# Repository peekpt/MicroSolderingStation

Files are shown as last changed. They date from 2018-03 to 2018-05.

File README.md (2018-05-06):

gif

# Micro Soldering Station

_Transform a cheap USB soldering iron in a powerfull Active tip Soldering Station._

**With almost no thermal capacity this station regulates the tip's temperature instantaneously. Solder larger thermal mass with ease, it's magic.**

_fiy: Active Soldering irons cost a lot of money_

*The cheapest Micro soldering Station ever:*

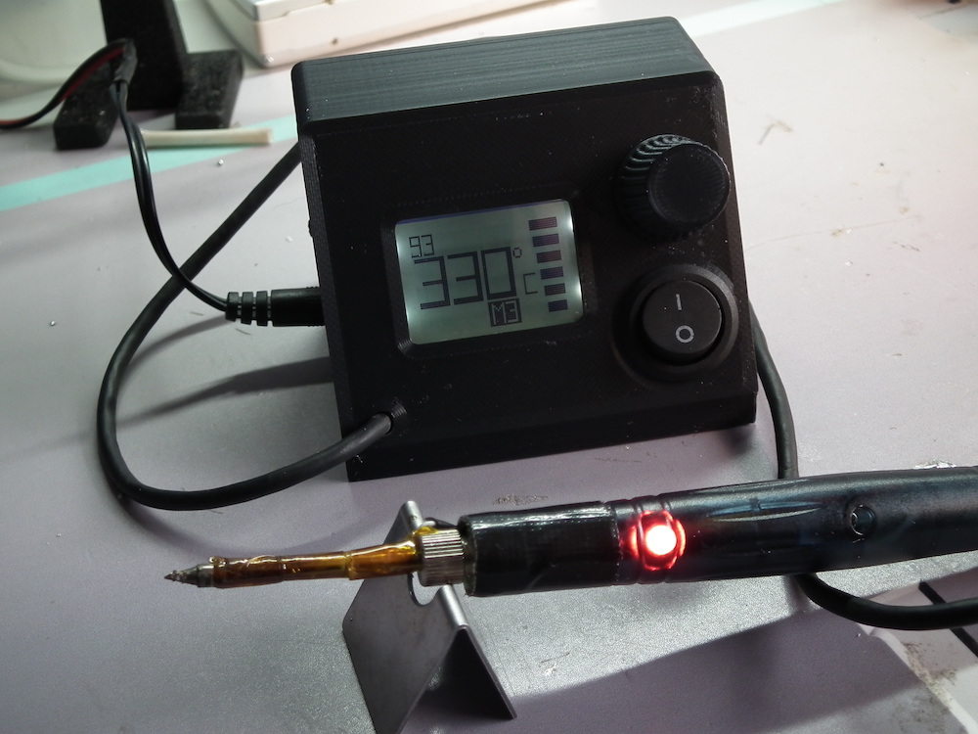
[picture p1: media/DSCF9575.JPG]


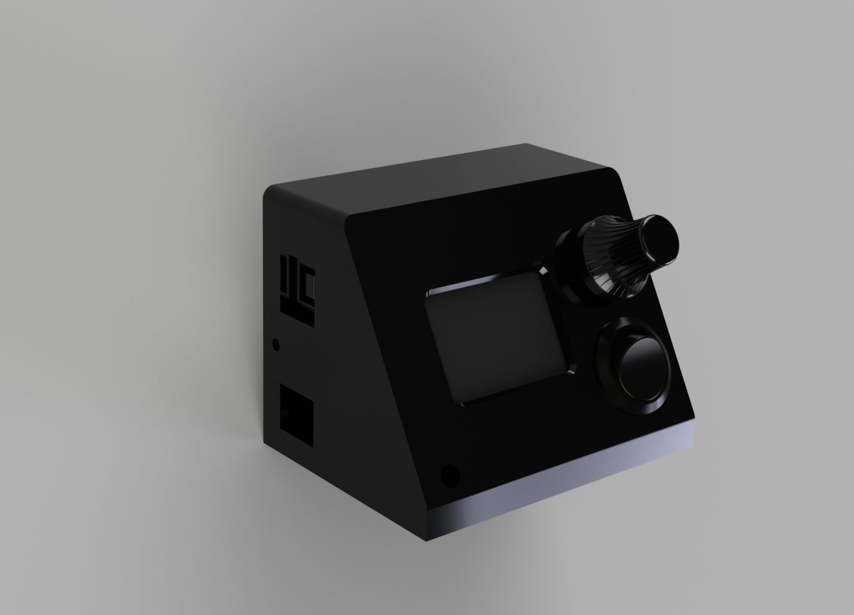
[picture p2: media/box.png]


## Youtube

YOUTUBE overview (https://www.youtube.com/watch?v=iJwf-qWp4lI)

YOUTUBE performance (https://www.youtube.com/watch?v=kRIv3psVogc)

## Features

- Cheap & easy build under 10$
- Temperature controled (PID)
- Memories
- Micro soldering tip
- Serial command interface
- Ploter (outputs usefull data) 
- Great User Interface with output power Bargraph
- UI Sounds, with temperature reached warning.
- Open Source Arduino based
- Firmware Updates
- 3D Printed Case
- Wake up from standby iron pickup detection (by temperature sensing)

## Materials

- 1x Arduino Uno
- 1x Nokia LCD Module
- 1x USB Soldering Iron
- 1x Thermistor 100k 3950
- 1x 4 wire wire cable(usb cable works)
- 1x 5mm Led
- 2x 1k resistor
- 1x 4,7k resitor
- 1x 10n Capacitor
- Kapton tape 10-20mm
- 1x N MosFet (or use the Iron's pcb one)
- 1x rocker switch
- 10 x small screws 2.5x5mm large head

## Schematic

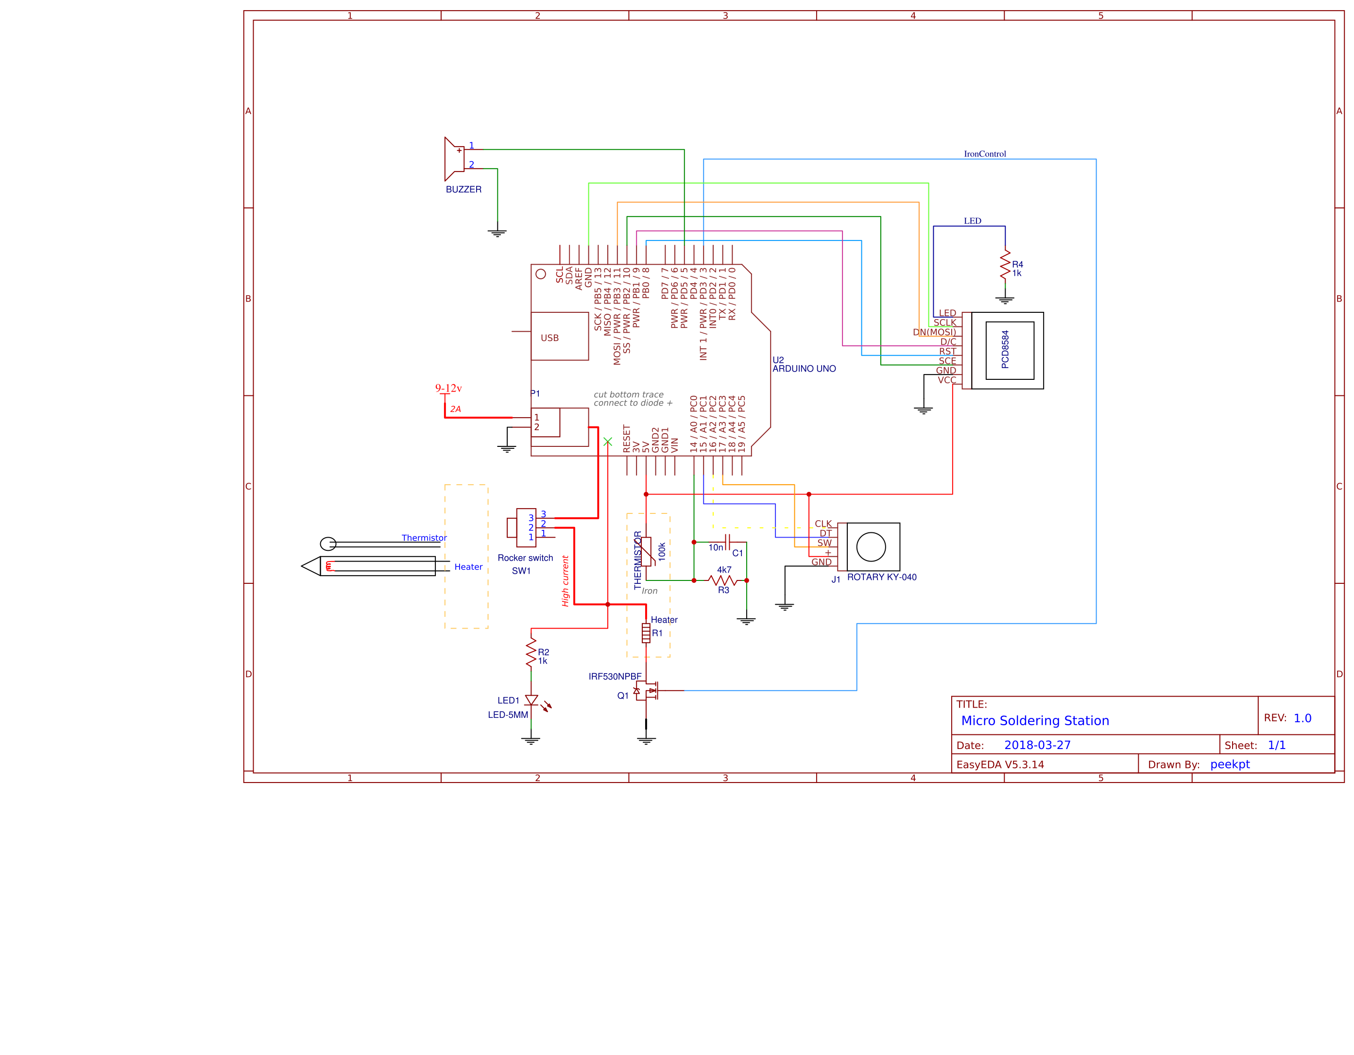
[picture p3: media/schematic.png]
Schematic


## Soldering Tip Diagram
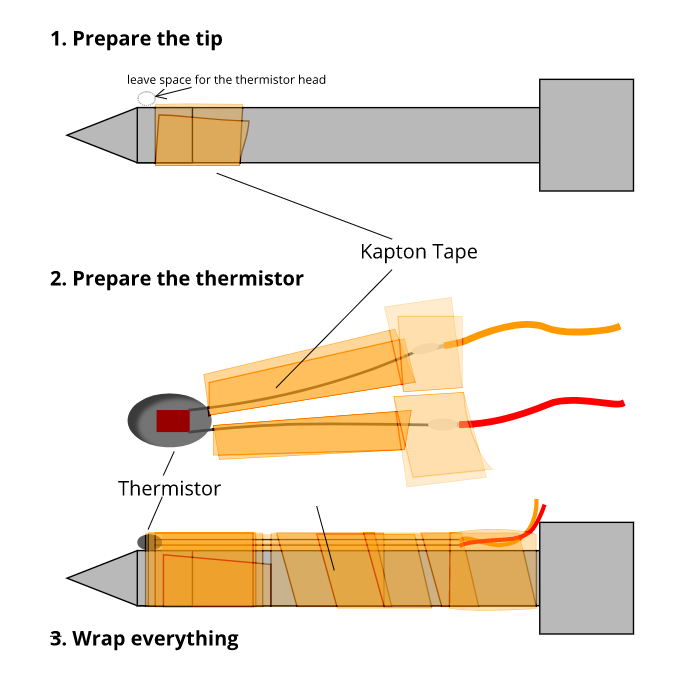
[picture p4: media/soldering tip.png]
Diagram


## UNO R3 CH340 Power Hack
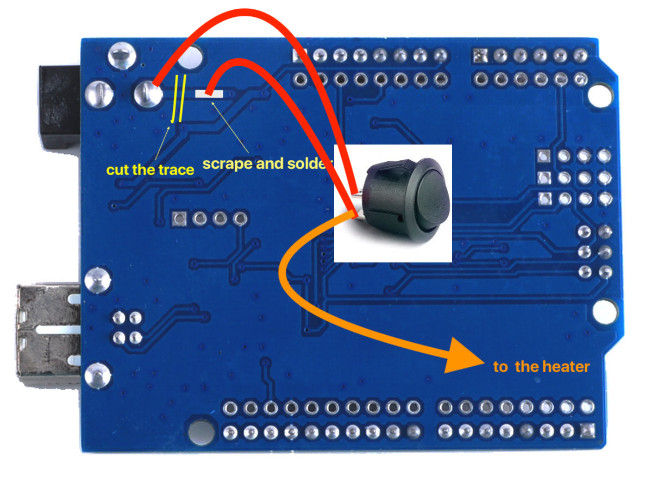
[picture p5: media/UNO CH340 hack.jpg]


_Cut Power the trace underneath the PCB and connect a rocker switch in series._

## Fritzing
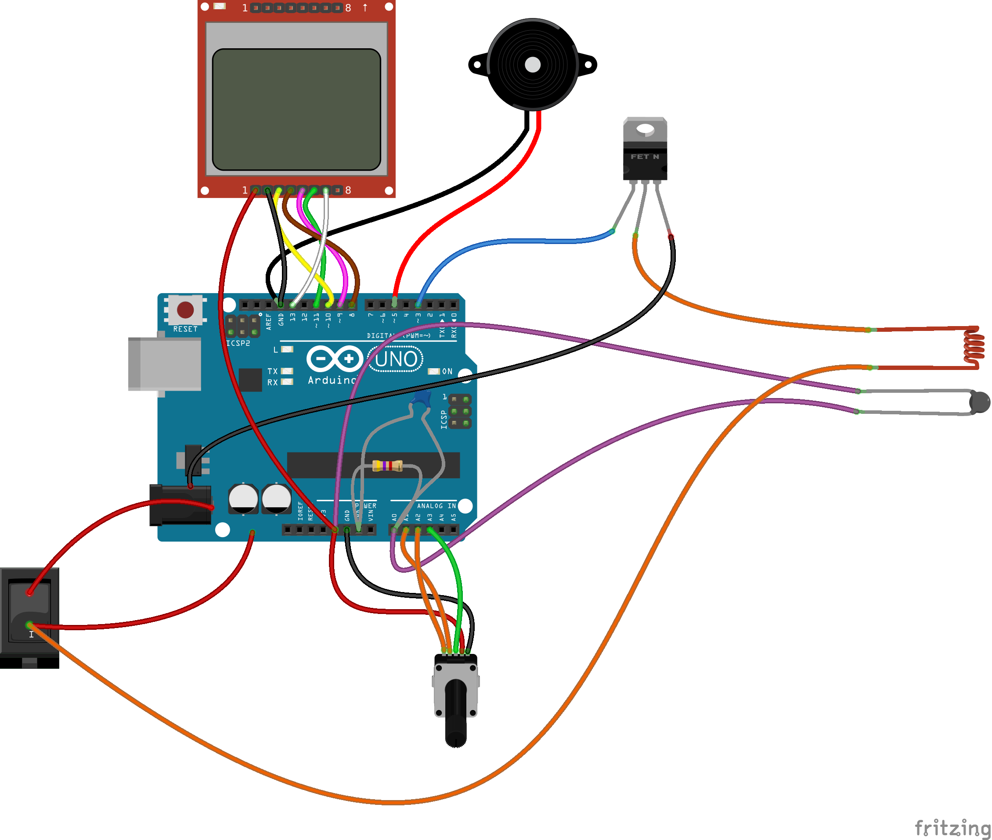
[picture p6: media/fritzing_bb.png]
Fritzing


Remove the pcb from the soldering iron and grab a cable with 4 wires (2 for thermistor, 2 for the heater).
Poke an hole in the side of the iron's case, near the yellow nut, to pass the 2 wires and solder them to the thermistor.
Use kapton tape to isolate the thermistor pins and to fix the thermistor's glass tip to the iron end with some kapton turns.
The other 2 wires connect to the heater and the led with a resistor in series. (watch the polarity of the led)
Remove the ball bearing and connect the led in the hole, break the spring post from the other side of the case.

## User Interface Screenshots
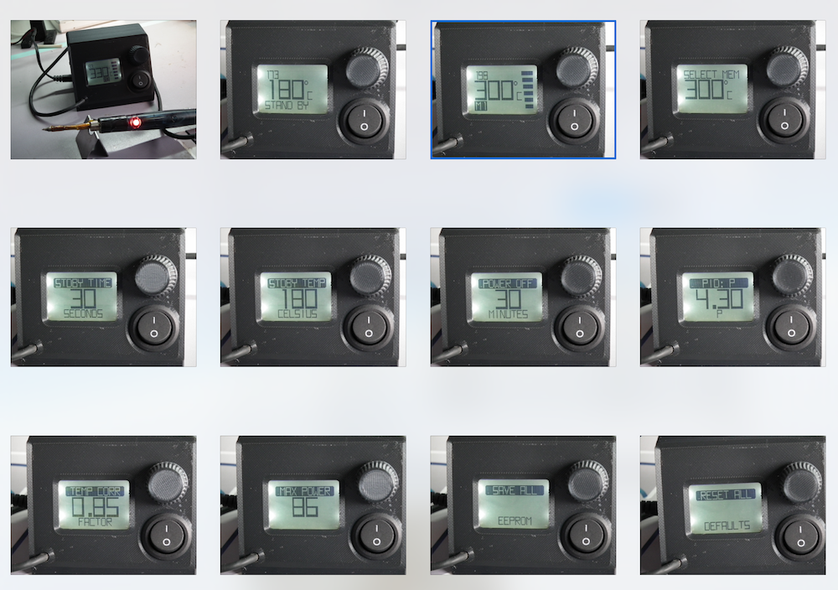
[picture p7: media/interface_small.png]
UNO


## Operation

**main view**

- \< >                   temp up down
- [click]                cycle memories
- [click & hold]         store mem mode
- [double click]         settings mode

**stand by mode**
- [click]                  leave standby mode

**store mem**
- \< >                   select memory to store
- [click]                store

**settings mode submenus**
 - \< >                   navigate submenus
 - [click]                edit submenu

**edit submenu**
- \< >                   change value up down
- [click]                exit submenu

## ChangeLog

2018-4-11

- interfance feedback sounds, you can disable on settings
- temperature reached beep 

2018-4-9

- improved automatic pickup detection (must be more improved in the future)
- you can now choose the type of wake up from standby between manual (by clicking) or automatic (by temperature) 

## Parts & Modules ##

100k thermistor (3950):

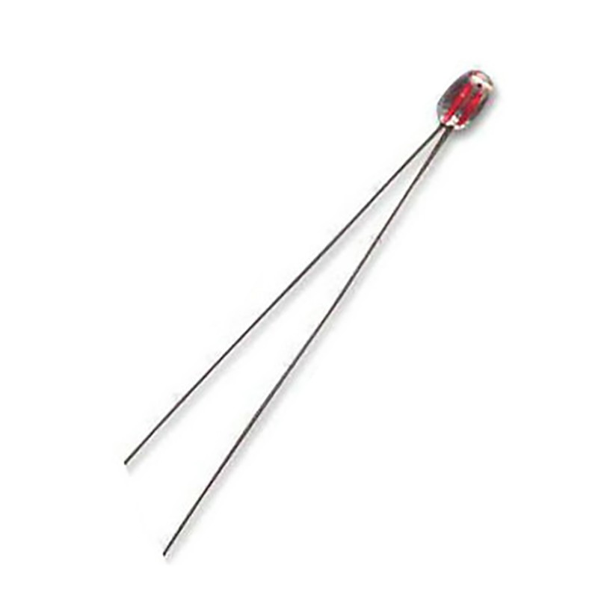
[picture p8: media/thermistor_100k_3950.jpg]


Arduino Uno R3 ch340:

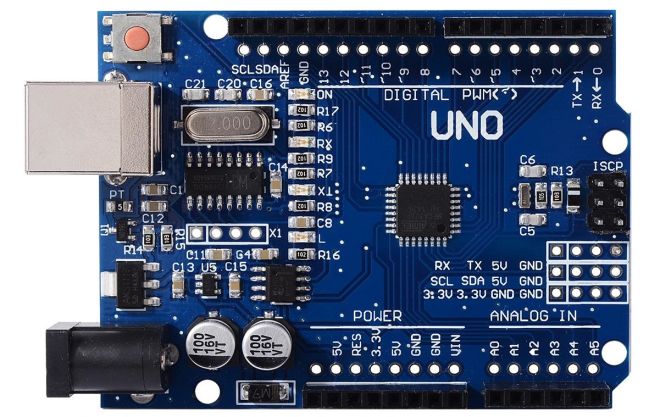
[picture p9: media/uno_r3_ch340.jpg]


Rotary Encoder:

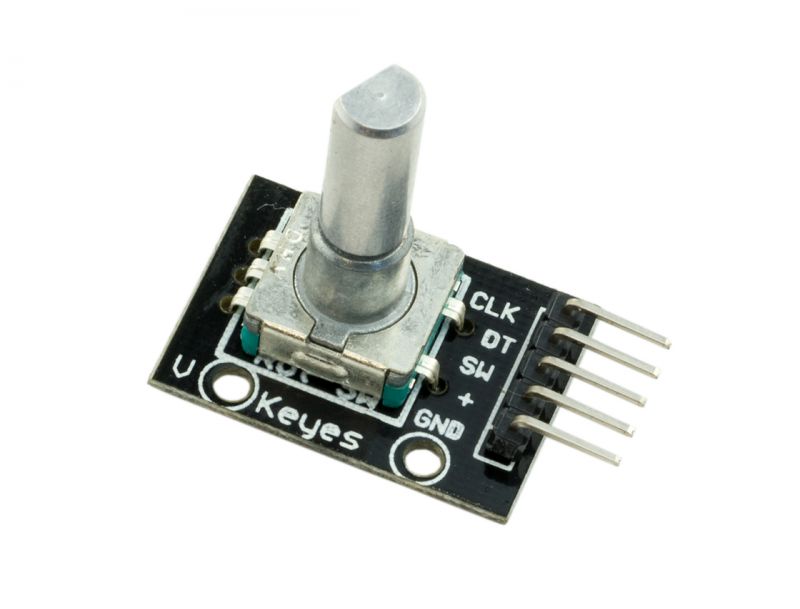
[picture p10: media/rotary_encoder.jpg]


USB Soldering Iron:

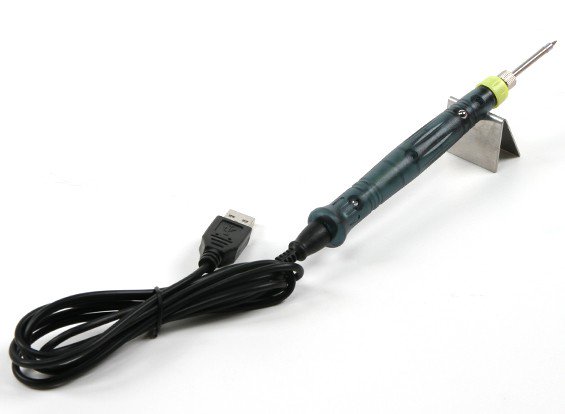
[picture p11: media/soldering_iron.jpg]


LCD:

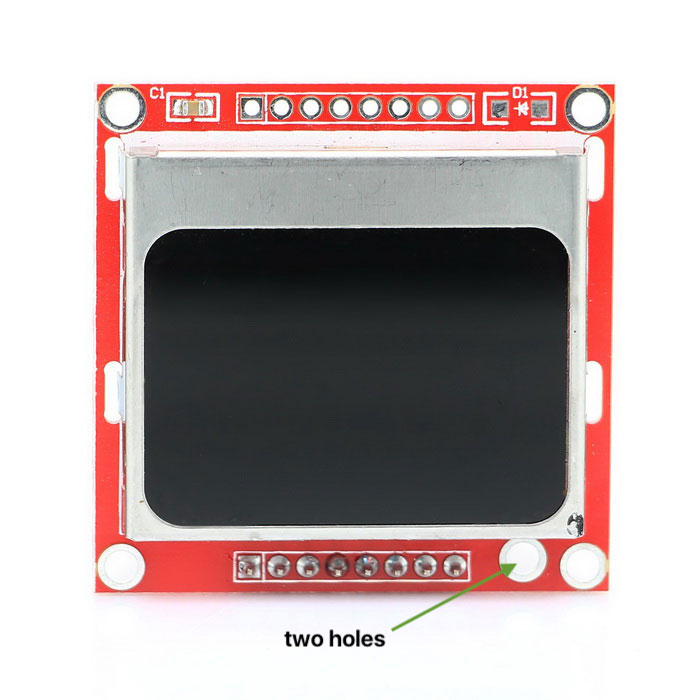
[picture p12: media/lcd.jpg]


Switch:

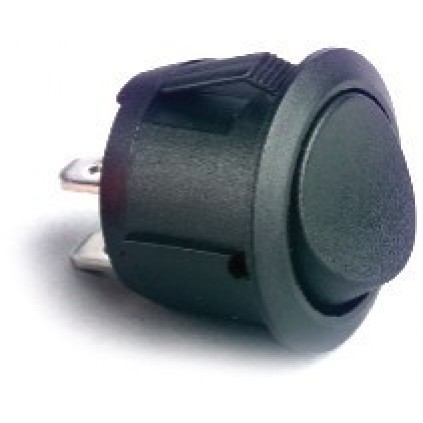
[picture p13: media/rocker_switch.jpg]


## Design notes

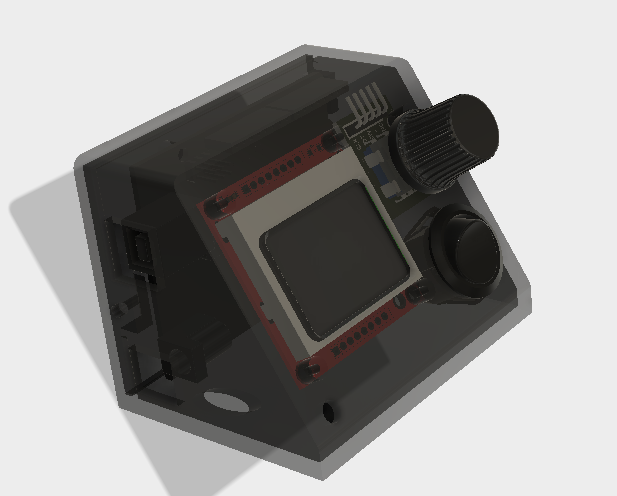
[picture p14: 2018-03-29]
media/transparent box.png

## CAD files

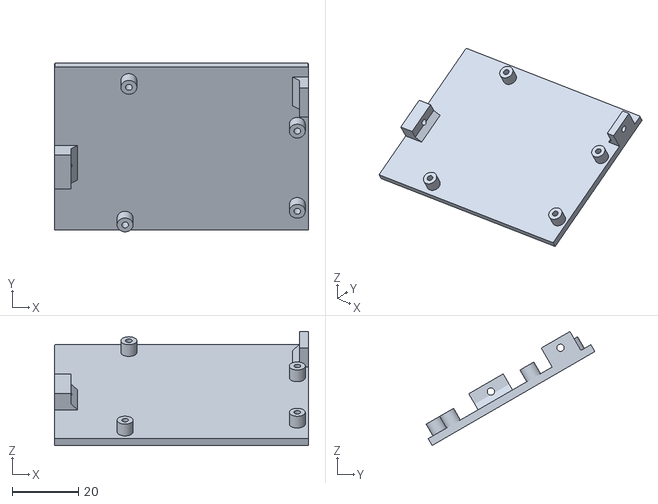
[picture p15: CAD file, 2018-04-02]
3D Box/soldering Station Box 2.stl
76.6 x 50.9 x 34.4

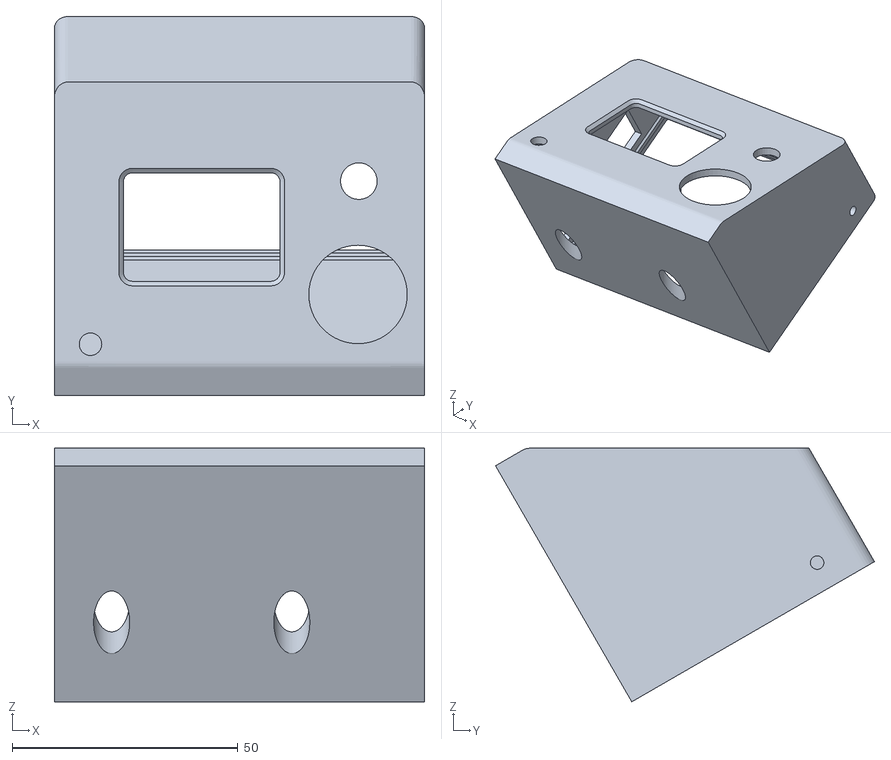
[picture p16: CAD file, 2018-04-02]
3D Box/soldering Station Box 1.stl
82.0 x 83.9 x 56.2

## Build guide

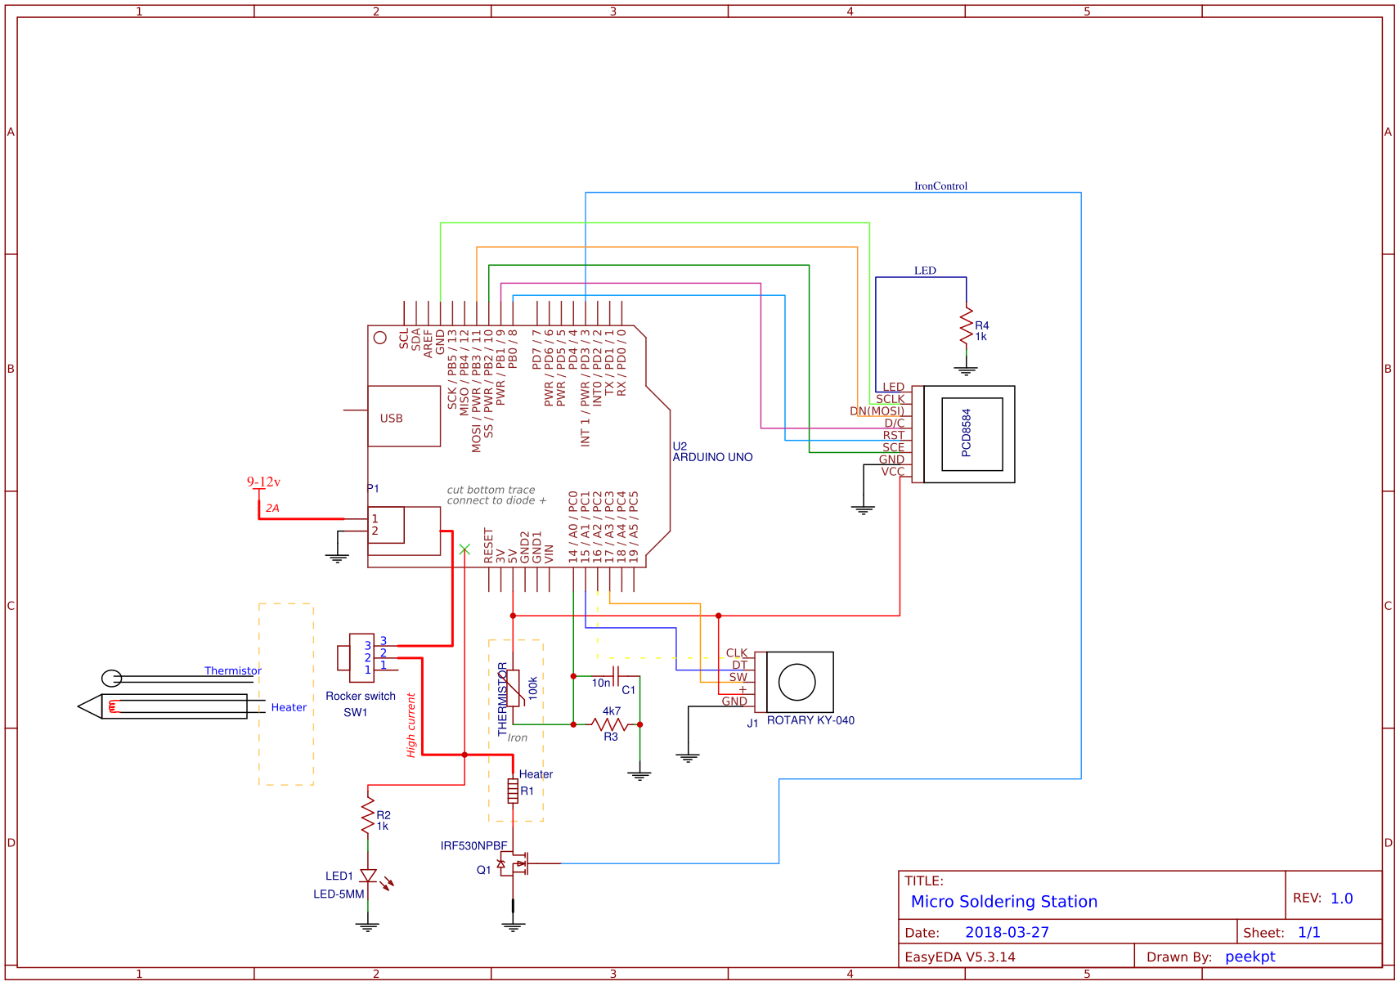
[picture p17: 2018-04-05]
media/Schematic_MicroSolderingStation_Micro-Soldering-Station_20180405173110.png

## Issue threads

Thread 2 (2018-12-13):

Power supply

caracolmaker, 2018-12-13:
What power source do you use for that project? I have a house from an old 12v and 1.5 amp laptop, would it work for the project?

peekpt, 2018-12-13:
Use platformio ide, open the folder and main.cpp then then plug your
Arduino and run

Na(o) quinta, 13/12/2018, 19:34, caracolmaker <notifications@github.com>
escreveu:

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

caracolmaker, 2018-12-15:
What power supply do you use foro this proyect.?

peekpt, 2018-12-15:
I use a simple 12v 2A wall charger, don't go over 14v the amp of the
Arduino uno can burn

caracolmaker <notifications@github.com> escreveu no dia sábado, 15/12/2018
à(s) 18:18:

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

caracolmaker, 2018-12-16:
Thank you

Closed 2018-12-16.

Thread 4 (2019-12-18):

Display problem

shark159, 2019-12-18:
Hello sir, I tried to compile this code for arduino nano,
i change some line and it compile and upload perfectly.
the problem is that after reboot the image stay on very frew seconds then disapear.
the conections are wired corectly,

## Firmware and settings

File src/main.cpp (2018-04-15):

#include <Arduino.h>
#include "SmoothThermistor.h"
#include <PID_v1.h>
#include <EEPROM.h>
#include <ClickEncoder.h>
#include <TimerOne.h>
#include <U8glib.h>
#include "avr/wdt.h"
#include "bitmap_logo.h"
#include "config.h"


enum VIEW { VIEW_LOGO, VIEW_MAIN, VIEW_SETTINGS } view;
enum MEM { MEM1, MEM2, MEM3 } mem;

const char *title[] = {"EXIT",   "STDBY TIME", "STDBY TEMP", "RESTORE",   "POWER OFF", "SOUNDS",   "PID: P",
                       "PID: I", "PID: D",     "TEMP CORR",  "MAX POWER", "SAVE ALL",  "RESET ALL"};
enum MENU {
  // it should match title array, this way it's easier to add more menus later
  MENU_EXIT = 0,
  MENU_SB_TIME,
  MENU_SB_TEMP,
  MENU_RESTORE,
  MENU_PWR_OFF,
  MENU_SOUND,
  MENU_P,
  MENU_I,
  MENU_D,
  MENU_T_CORR,
  MENU_MAX_PWR,
  MENU_SAVE_ALL,
  MENU_RESET_ALL,
  MENU_LENGHT // easy way having the menu lenght
} menu_e;
byte menuPosition;

byte memoryToStore;
ClickEncoder *encoder;
int16_t encLast, encValue;

double Setpoint, Input, Output, serialMillis, lcdMillis, logoMillis, blinkMillis, functionTimeout, standByMillis,
    tempBeforeEnteringStandby;
bool isDisplayingLogo, blink, isSavingMemory, isOnStandBy, isPlotting;

// measuring the temp variation per second
double tempVariation;
double oldTemp;
double tempMillis;
bool beepAtSetpoint;

// settings menu vars;
bool isEditing;
const char *topText;
const char *bottomText;
bool isFastCount;
int i;
double d;

typedef struct EepromMap {
  byte firstBoot;     // check for a number 123
  double standbyTemp; // temperature on stand-by
  unsigned int standbyTime;
  double p;           // p
  double i;           // i
  double d;           // d
  double m1;          // memory 1
  double m2;          // memory 2
  double m3;          // memory 3
  double tCorrection; // thermistor reading temperature correction factor
  byte maxPower;
  unsigned int timeout; //  seconds to standby
  byte lastMem;         // lastMemory selected
  bool sound;           // sound on /off
  bool restore;         // 0 manual 1 auto

} eeprom_map_t;

eeprom_map_t settings;


U8GLIB_PCD8544 u8g(LCD_CS,LCD_A0, LCD_RST); // uses 13 ,11 as Hardware pins 10-CS 9-A0 8-RS

// void setPwmFrequency(int, int); // sets pwm frequency divisor
double getTemp();             // read thermistor temp
void resetFailSafe();         // reset all eeprom to default
void printTunnings();         // outputs de pid settings
void draw();                  // displays a view
void updateLCD();             // updateLCD
void viewLogo();              // logo view
void viewMain();              // main view layout
void viewSettings();          // settings view layout
void software_Reboot();       // reboots
void timerIsr();              // rotary switch interrupt
void rotaryMain();            // rotary Main routines
void cicleMem();              // cicle ...MEM1->MEM2->MEM3->MEM1...
void resetTimeouts();         // reset    all timouts running to millis()
void drawMemIcon(byte);       // draws the given memory icon
void resetStandby();          // reset standby time count down
void rotarySettings();        // process rotary on the settings view
void drawTitle(const char *); // draws the title inverse bar on the settings menu
void beep();                  // sound 
void beepBeep();
void beepBop();
void bop();
void bopLong();

SmoothThermistor therm(SENSOR_PIN,      // the analog pin to read from
                       ADC_SIZE_10_BIT, // the ADC size
                       100000,          // the nominal resistance
                       4700,            // the series resistance
                       3950,            // the beta coefficient of the thermistor
                       25,              // the temperature for nominal resistance
                       10);             // the number of samples to take for each measurement

PID myPID(&Input, &Output, &Setpoint, 0, 0, 0, DIRECT);

void setup() {
  Serial.begin(9600);
  Serial.println(F("* START *"));

  tempVariation = 0;
  oldTemp = getTemp();
  // input and output pins
  pinMode(SENSOR_PIN, INPUT);
  pinMode(HEATER_PIN, OUTPUT);
  pinMode(BUZZER_PIN, OUTPUT);

  // rotary encoder
  encoder = new ClickEncoder(A1, A2, A3); // A, B, BTN
  encoder->setAccelerationEnabled(true);
  Timer1.initialize(1000);
  Timer1.attachInterrupt(timerIsr);
  // encLast = -1;
  encLast = encValue = encoder->getValue();

  // LCD
  u8g.setColorIndex(1);
  view = VIEW_LOGO; // display logo view.
  updateLCD();
  isDisplayingLogo = true;

  // heater
  // setPwmFrequency(HEATER_PIN, 1);
  analogWrite(HEATER_PIN, 0); // set heater to 0

  lcdMillis = serialMillis = logoMillis = blinkMillis = standByMillis = millis(); // delay routines

  // Load EEPROM
  EEPROM.get(0, settings);
  if (settings.firstBoot != 123) { // if the check number is not present then save settings
    resetFailSafe();
  }
  myPID.SetTunings(settings.p, settings.i, settings.d);
  printTunnings();

  Input = getTemp();
  //  choose last selected memory setpoint temperature
  switch (settings.lastMem) {
  case MEM1:
    Setpoint = settings.m1;
    break;
  case MEM2:
    Setpoint = settings.m2;
    break;
  case MEM3:
    Setpoint = settings.m3;
    break;
  default:
    Setpoint = 150;
  }
  tempBeforeEnteringStandby = Setpoint;

  myPID.SetMode(AUTOMATIC);                    // enable pid controller
  myPID.SetOutputLimits(0, settings.maxPower); // limits heater pwm duty cycle

  u8g.setColorIndex(0);
  u8g.drawBox(0, 0, 84, 48);
  u8g.setColorIndex(1);
  blink = false;
  isSavingMemory = false;
  memoryToStore = settings.lastMem;
  functionTimeout = 0;
  isOnStandBy = false;
  menuPosition = 0;
  isFastCount = false;
  isPlotting = false;
  beepAtSetpoint = true;
  beep();
}

void loop() {
  // serial input control
  if (Serial.available() > 0) {
    String strInput = Serial.readString();
    String command = strInput.substring(0, 2);
    double value = strInput.substring(2, strInput.length()).toDouble();
    if (command == "p:") {
      Serial.print(F("changed P value to: "));
      myPID.SetTunings(value, myPID.GetKi(), myPID.GetKd());
      Serial.println(myPID.GetKp());
    } else if (command == "i:") {
      Serial.print(F("changed I value to: "));
      myPID.SetTunings(myPID.GetKp(), value, myPID.GetKd());
      Serial.println(myPID.GetKi());
    } else if (command == "d:") {
      Serial.print(F("changed D value to: "));
      myPID.SetTunings(myPID.GetKp(), myPID.GetKi(), value);
      Serial.println(myPID.GetKd());
    } else if (command == "t") {
      printTunnings();
    } else if (command == "t:") {
      Serial.print(F("Setpoint: "));
      Setpoint = value;
      Serial.println(Setpoint);
    } else if (command == "s") {
      // save settings
      settings.p = myPID.GetKp();
      settings.i = myPID.GetKi();
      settings.d = myPID.GetKd();
      EEPROM.put(0, settings);
      Serial.println(F("Settings saved!"));
    } else if (command == "r") {
      resetFailSafe();
    } else if (command == "pl") {
      isPlotting = !isPlotting;
    } else {
      Serial.println(F("Unknown command!"));
    }
  }

  // rotary
  if (view == VIEW_MAIN) {
    rotaryMain();
  } else if (view == VIEW_SETTINGS) {
    rotarySettings();
  }

  // logo delay
  if (isDisplayingLogo) {
    if (millis() - logoMillis > 2000) { // show logo for 4 seconds
      view = VIEW_MAIN;
      isDisplayingLogo = false;
      updateLCD();
      resetStandby();
    }
  }

  // standby time
  if (!isOnStandBy) {
    if (millis() - standByMillis > (1000 * settings.standbyTime)) {
      tempBeforeEnteringStandby = Setpoint;
      Setpoint = settings.standbyTemp;
      isOnStandBy = true;

    }
  }

  // Control temperature
  Input = getTemp();
  if (Input < 0 || Input > 450) { // some protection
    myPID.SetMode(MANUAL);
    analogWrite(HEATER_PIN, 0);
    pinMode(HEATER_PIN, INPUT);
    view = VIEW_LOGO;
  }
  myPID.Compute();
  analogWrite(HEATER_PIN, Output);

  // LCD Update
  if (millis() - lcdMillis > 250) { // lcd update delay
    blink = !blink;
    updateLCD();
    lcdMillis = millis();
  }

  // function timeout
  if (millis() - functionTimeout > 20000) {
    // only permits 20 seconds without action outside main
    // functionTimeout needs to be reset to millis() in every rotary event
    // or it will call main screen
    isSavingMemory = false;
    view = VIEW_MAIN;

    updateLCD();
  }

  // temperature delta per second
  if (millis() - tempMillis > 1000) {
    double newTemp = getTemp();
    tempVariation = (newTemp / oldTemp) - 1;
    oldTemp = newTemp;
    tempMillis = millis();
  }

  // detect temperature drop and reset standby
  // if auto restore is enabled
  if (isOnStandBy) { // if on standby

    if (settings.restore) { // if on auto restore

      double powerOut = Output / settings.maxPower * 100;
      if (tempVariation < -0.032 && powerOut < 0.05) {
        // while is dropping power is 0 detects and excessive cooling
        resetStandby();
      } else if (tempVariation < -0.025 && powerOut > 9) {
        // while temp is maintaining the standby, power is oscilating and positive variation too
        resetStandby();
      }
    }
  } else if (tempVariation > 0.02) { // if not on standby detect lower drops
    resetStandby();
  }

  // Plotter
  if (millis() - serialMillis > 1000 && isPlotting) { // Plot values
    const char *spacer = " ";
    Serial.print(Setpoint);
    Serial.print(spacer);
    Serial.print(Input);
    Serial.print(spacer);
    Serial.print(Output / settings.maxPower * 100);
    Serial.print(spacer);
    Serial.print(myPID.GetKp());
    Serial.print(spacer);
    Serial.print(myPID.GetKi());
    Serial.print(spacer);
    Serial.print(myPID.GetKd());
    Serial.print(spacer);
    Serial.print(isOnStandBy);
    Serial.print(spacer);
    Serial.print(settings.standbyTemp);
    Serial.print(spacer);
    Serial.print(settings.standbyTime);
    Serial.print(spacer);
    Serial.println(tempVariation, 5);

    serialMillis = millis();
  }

  if (!isOnStandBy && beepAtSetpoint && Input >= Setpoint-5 && settings.sound){
    // beeps once when Input reached setpoint 
    beepAtSetpoint = false;
    beep();
  }
}

void resetFailSafe() {
  settings.firstBoot = 123;
  settings.standbyTemp = SETTINGS_STANDBY_TEMP;
  settings.standbyTime = SETTINGS_STANDBY_TIME;
  settings.p = SETTINGS_P;
  settings.i = SETTINGS_I;
  settings.d = SETTINGS_D;
  settings.m1 = SETTINGS_M1;
  settings.m2 = SETTINGS_M2;
  settings.m3 = SETTINGS_M3;
  settings.tCorrection = SETTINGS_TEMP_CORRECTION;
  settings.maxPower = SETTINGS_MAX_POWER;
  settings.timeout = SETTINGS_TIMEOUT;
  settings.lastMem = MEM1;
  settings.sound = SETTINGS_SOUND;
  settings.restore = SETTINGS_RESTORE;
  myPID.SetTunings(settings.p, settings.i, settings.d);
  EEPROM.put(0, settings); // save values to eeprom
  Serial.println(F("Reseted!"));
  delay(500);
  software_Reboot();
}

void printTunnings() {
  Serial.print(F("The tunings  P: "));
  Serial.print(myPID.GetKp());
  Serial.print(F(", I: "));
  Serial.print(myPID.GetKi());
  Serial.print(F(", D: "));
  Serial.println(myPID.GetKd());
}


void software_Reboot() {
  wdt_enable(WDTO_15MS);
  while (1) {
  }
}

void timerIsr() { encoder->service(); }

void draw() {
  // graphic commands to redraw the complete screen should be placed here
  u8g.setContrast(110);

  switch (view) {
  case VIEW_LOGO:
    viewLogo();
    break;
  case VIEW_MAIN:
    viewMain();
    break;
  case VIEW_SETTINGS:
    viewSettings();
    break;
  default:
    break;
  }
}

void updateLCD() {
  u8g.firstPage();
  do {
    draw();
  } while (u8g.nextPage());
}

// views layout
void viewLogo() { u8g.drawXBMP(0, 0, 84, 48, bitmap_logo); }
void viewMain() {

  // common main view mode drawing
  // temperature
  u8g.setColorIndex(1);
  u8g.setFont(u8g_font_freedoomr25n);
  u8g.drawStr(0, 37, String((int)Setpoint).c_str());
  u8g.drawCircle(59, 14, 2);
  u8g.setFont(u8g_font_freedoomr10r);
  u8g.drawStr(61, 37, "C");
  if (!isSavingMemory) {
    // render main view - normal
    u8g.setColorIndex(1);
    u8g.setFont(u8g_font_freedoomr10r);
    u8g.drawStr(0, 12, String((int)(Input + 0.5)).c_str());

    // draw pwr-meter
    // unit bar height is 5px, 8 boxes separated by 2px
    byte unit = settings.maxPower / 8; // max power in settings divided 8 bars
    // draw power barstop to bottom
    if (Output > (settings.maxPower - unit)) {
      u8g.drawBox(68, 0, 16, 5);
    }
    if (Output > (settings.maxPower - (2 * unit))) {
      u8g.drawBox(69, 8, 15, 5);
    }
    if (Output > (settings.maxPower - (3 * unit))) {
      u8g.drawBox(70, 16, 14, 5);
    }
    if (Output > (settings.maxPower - (4 * unit))) {
      u8g.drawBox(71, 24, 13, 5);
    }
    if (Output > (settings.maxPower - (5 * unit))) {
      u8g.drawBox(72, 32, 12, 5);
    }
    if (Output > (settings.maxPower - (6 * unit))) {
      u8g.drawBox(73, 40, 11, 5);
    }
    if (Output > (settings.maxPower - (7 * unit))) {
      u8g.drawBox(74, 48, 10, 5);
    }

    // draw the memory icon

    if (!isOnStandBy) {
      if (Setpoint == settings.m1) {
        drawMemIcon(MEM1);
        settings.lastMem = MEM1;
      } else if (Setpoint == settings.m2) {
        drawMemIcon(MEM2);
        settings.lastMem = MEM2;
      } else if (Setpoint == settings.m3) {
        drawMemIcon(MEM3);
        settings.lastMem = MEM3;
      }
    } else {
      u8g.drawStr(0, 49, "STAND BY");
    }

  } else {

    // render main view - store
    u8g.setColorIndex(1);
    u8g.setFont(u8g_font_freedoomr10r);
    u8g.drawStr(0, 12, "SELECT MEM");

    if (blink) { // blink the memory icon
      drawMemIcon(memoryToStore);
    }
  }
}
void viewSettings() {
  switch (menuPosition) {
    char topBuf[8];
  case MENU_EXIT: // exit
    topText = "";
    bottomText = "REBOOT";
    break;
  case MENU_SB_TIME: // stand by time
    topText = dtostrf(settings.standbyTime + 0.0f, 0, 0, topBuf);
    bottomText = "SECONDS";
    break;
  case MENU_SB_TEMP: // stand by temperature
    topText = dtostrf(settings.standbyTemp + 0.0f, 0, 0, topBuf);
    bottomText = "CELSIUS";
    break;
  case MENU_RESTORE: // restore temperature
    topText = "";
    bottomText = (settings.restore) ? "AUTO" : "MANUAL";
    break;
  case MENU_PWR_OFF: // power off
    topText = dtostrf(settings.timeout + 0.0f, 0, 0, topBuf);
    bottomText = "MINUTES";
    break;
  case MENU_SOUND:
    topText = "";
    bottomText = (settings.sound) ? "ON" : "OFF";
    break;
  case MENU_P: // P
    topText = dtostrf(settings.p, 0, 2, topBuf);
    bottomText = "P";
    break;
  case MENU_I: // I
    topText = dtostrf(settings.i, 0, 2, topBuf);
    bottomText = "I";
    break;
  case MENU_D: // D
    topText = dtostrf(settings.d, 0, 2, topBuf);
    bottomText = "D";
    break;
  case MENU_T_CORR: // temp correction
    topText = dtostrf(settings.tCorrection, 0, 2, topBuf);
    bottomText = "FACTOR";
    break;
  case MENU_MAX_PWR: // max power
    topText = dtostrf(map(settings.maxPower, 0, 255, 0, 100) + 0.0f, 0, 0, topBuf);
    bottomText = "%";
    break;
  case MENU_SAVE_ALL: // save
    topText = "";
    bottomText = "EEPROM";
    break;
  case MENU_RESET_ALL: // reset
    topText = "";
    bottomText = "DEFAULTS";
    break;
  default:
    topText = "";
    bottomText = "";
    break;
  }

  // render the view
  drawTitle(title[menuPosition]);
  u8g.setColorIndex(1);
  u8g.setFont(u8g_font_freedoomr25n);
  if (isEditing) {
    if (blink) {
      u8g.drawStr(42 - (u8g.getStrWidth(topText) / 2), 39, topText); // center
    }
  } else {
    u8g.drawStr(42 - (u8g.getStrWidth(topText) / 2), 39, topText);
  }
  u8g.setFont(u8g_font_freedoomr10r);
  if (isEditing && topText == "") {
    if (blink) {
      u8g.drawStr(42 - (u8g.getStrWidth(bottomText) / 2), 50, bottomText);
    }
  } else {
    u8g.drawStr(42 - (u8g.getStrWidth(bottomText) / 2), 50, bottomText);
  }

}

// rotary behaviour
void rotaryMain() {

  encValue += encoder->getValue();
  if (isOnStandBy) {
    encLast = encValue;
  }
  if (encValue != encLast) {
    bop();

    resetStandby();
    if (encValue > encLast) {
      if (!isSavingMemory) {
        Setpoint = constrain(Setpoint + (5 * (encValue - encLast)), 100, 400);
      } else {
        memoryToStore = constrain(memoryToStore + 1, 0, 2);
      }
    }
    if (encValue < encLast) {
      if (!isSavingMemory) {
        Setpoint = constrain(Setpoint - (5 * (encLast - encValue)), 100, 400);
      } else {
        memoryToStore = constrain(memoryToStore - 1, 0, 2);
      }
    }

    encLast = encValue;
    updateLCD();
  }

  ClickEncoder::Button b = encoder->getButton();

  if (b == ClickEncoder::Clicked) {

    void resetTimeouts();
    if (isOnStandBy) {

      resetStandby();
      return;
    }
    if (!isSavingMemory) {
          beep();
      cicleMem();
    } else {
      switch (memoryToStore) {
      case MEM1:
        settings.m1 = Setpoint;
        settings.lastMem = MEM1;
        break;
      case MEM2:
        settings.m2 = Setpoint;
        settings.lastMem = MEM2;
        break;
      case MEM3:
        settings.m3 = Setpoint;
        settings.lastMem = MEM3;
        break;
      default:
        break;
      }
      EEPROM.put(0, settings);
      Serial.println("Memory Saved!");
      isSavingMemory = false;
          bopLong();
    }
  }
  if (b == ClickEncoder::Held) {
    
    if (!isSavingMemory) {
      resetTimeouts();
      isSavingMemory = true;
      beepBop();
    }
  }
  if (b == ClickEncoder::DoubleClicked) {
    beepBeep();
    resetTimeouts();
    // Serial.println("double clicked");
    view = VIEW_SETTINGS;
  }
}

void rotarySettings() {
  ClickEncoder::Button b = encoder->getButton();
  encValue += encoder->getValue();

  if (encValue != encLast) {
    bop();
    resetTimeouts();

    if (encValue > encLast) {
      if (!isEditing) { // if is not editing increment menu
        menuPosition = constrain(menuPosition + 1, 0, MENU_LENGHT - 1);
      } else {

        // increment value
        switch (menuPosition) {
        case MENU_SB_TIME:
          settings.standbyTime = constrain(settings.standbyTime + 5, 30, 300);
          break;
        case MENU_SB_TEMP:
          i = (isFastCount) ? 10 : 5;
          settings.standbyTemp = constrain(settings.standbyTemp + i, 0, 250);
          break;
        case MENU_RESTORE:
          settings.restore = true;
          break;
        case MENU_PWR_OFF:
          settings.timeout = constrain(settings.timeout + 10, 10, 120);
          break;
        case MENU_SOUND:
          settings.sound = true;
          break;
        case MENU_P:
          d = (isFastCount) ? 1 : 0.01;
          settings.p = constrain(settings.p + d, 0, 30);
          break;
        case MENU_I:
          d = (isFastCount) ? 1 : 0.01;
          settings.i = constrain(settings.i + d, 0, 30);
          break;
        case MENU_D:
          d = (isFastCount) ? 1 : 0.01;
          settings.d = constrain(settings.d + d, 0, 30);
          break;
        case MENU_T_CORR:
          settings.tCorrection = constrain(settings.tCorrection + 0.01, 0.5, 1.5);
          break;
        case MENU_MAX_PWR:
          settings.maxPower = constrain(settings.maxPower + 2, 50, 255);
          break;
        default:
          break;
        }
      }
    }
    if (encValue < encLast) {
      if (!isEditing) { // if is not editing decrement menu
        menuPosition = constrain(menuPosition - 1, 0, MENU_LENGHT - 1);
      } else {
        // decrement value

        switch (menuPosition) {
        case MENU_SB_TIME:
          settings.standbyTime = constrain(settings.standbyTime - 5, 30, 300);
          break;
        case MENU_SB_TEMP:
          i = (isFastCount) ? 10 : 5;
          settings.standbyTemp = constrain(settings.standbyTemp - i, 0, 250);
          break;
        case MENU_RESTORE:
          settings.restore = false;
          break;
        case MENU_PWR_OFF:
          settings.timeout = constrain(settings.timeout - 10, 10, 120);
          break;
        case MENU_SOUND:
          settings.sound = false;
          break;
        case MENU_P:
          d = (isFastCount) ? 1 : 0.01;
          settings.p = constrain(settings.p - d, 0, 30);
          break;
        case MENU_I:
          d = (isFastCount) ? 1 : 0.01;
          settings.i = constrain(settings.i - d, 0, 30);
          break;
        case MENU_D:
          d = (isFastCount) ? 1 : 0.01;
          settings.d = constrain(settings.d - d, 0, 30);
          break;
        case MENU_T_CORR:
          settings.tCorrection = constrain(settings.tCorrection - 0.01, 0.5, 1.5);
          break;
        case MENU_MAX_PWR:
          settings.maxPower = constrain(settings.maxPower - 2, 50, 255);
          break;
        default:
          break;
        }
      }
    }
    blink = true;
    updateLCD();
    blink = true;
  }
  encLast = encValue;
  // on click
  if (b == ClickEncoder::Clicked) {
    beep();
    resetTimeouts();
    if (menuPosition == MENU_EXIT && !isEditing) { // exit
      software_Reboot();
    } else if (menuPosition == MENU_RESET_ALL && !isEditing) { // reset
      resetFailSafe();
    } else if (menuPosition == MENU_SAVE_ALL && !isEditing) { // save
      EEPROM.put(0, settings);
      delay(100);
      software_Reboot();
    }

    isEditing = !isEditing;
  }
  if (b == ClickEncoder::Held) {

    isFastCount = true;

  } else {
    isFastCount = false;
  }
}

void cicleMem() {
  switch (settings.lastMem) {
  case MEM1:
    settings.lastMem = MEM2;
    Setpoint = settings.m2;
    break;
  case MEM2:
    settings.lastMem = MEM3;
    Setpoint = settings.m3;
    break;
  case MEM3:
    settings.lastMem = MEM1;
    Setpoint = settings.m1;
  default:
    break;
  }

  // EEPROM.put(0,settings); //save
}

void resetTimeouts() { functionTimeout = millis(); }
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

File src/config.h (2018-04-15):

#ifndef CONFIG_H
#define CONFIG_H

// PINS 

#define HEATER_PIN 3 // must be PWM capable
#define SENSOR_PIN A0 
#define BUZZER_PIN 5

#define LCD_CS 10
#define LCD_A0 9
#define LCD_RST 8


// DEFAULT_SETTINGS

#define SETTINGS_STANDBY_TEMP 150 // Celsius
#define SETTINGS_STANDBY_TIME 60  // seconds
#define SETTINGS_P 4.5 // proportional
#define SETTINGS_I 0 // integral
#define SETTINGS_D 2.0 // derivatinve
#define SETTINGS_M1 300 // memory M1 
#define SETTINGS_M2 260 // memory M2
#define SETTINGS_M3 350 // memory M3
#define SETTINGS_TEMP_CORRECTION 0.85 //tip's temperature relative to thermistor reading
#define SETTINGS_MAX_POWER 220 // 0-255 max PWM output power (0-100% in the menu)
#define SETTINGS_TIMEOUT 30 // minutes before shutoff
#define SETTINGS_SOUND 1 // 0 to disable , 1 to enable
#define SETTINGS_RESTORE 1 // restore froms standby 0 MANUAL(by clicking), 1 AUTO (by temperature variation)






#endif

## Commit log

2018-03-27 + schematic image
2018-03-29 working on the settings menu, Reset and Save done.
    [main.cpp]
2018-04-05 new schematic
2018-04-05 polishing the source code
    [fritzing.fzz]
2018-04-11 added Interface sounds (buzzer on pin 5) with temperature reach beep
    [fritzing.fzz]
2018-05-06 added dependencies list
    [soldering Station Box 1.stl, soldering Station Box 2.stl]
